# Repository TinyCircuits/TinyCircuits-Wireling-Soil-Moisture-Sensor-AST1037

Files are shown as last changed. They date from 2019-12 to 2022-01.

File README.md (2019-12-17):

# TinyCircuits Wireling Soil Moisture Sensor
# AST1037 Rev1

The design files are located under design_files/ for the TinyCircuits AST1037 Rev 1 PCB. This is a Wireling board which etects moisture in soil using the ATTiny25 and this plant tag shaped Whisker so you never have to guess when to water!

Format is in Cadsoft Eagle format - Eagle version 6.2 was used for the original design.

For more infomation on this, check out the product page at TinyCircuits.com

# License:

Design by TinyCircuits.
All design files are released under the Creative Commons Attribution Share-Alike 3.0 License, see the following link for details: http://creativecommons.org/licenses/by-sa/3.0

All text above must be included in any redistribution or derived design

This project uses designs and concepts developed as part of the Arduino project and the LilyPad project.  The TinyCircuits design files themselves (schematics, PCB and libraries) are not directly derived from these works' design files and have been created new, however the concepts and basic architecture behind the TinyDuino and TinyLily products are derived and we thank the hard work of the organizations below for their contributions to open-source hardware:
  
Original Arduino Uno Design by Team Arduino

LilyPad Arduino Design by Leah Buechley and Sparkfun Electronics

Please support the open-source hardware community

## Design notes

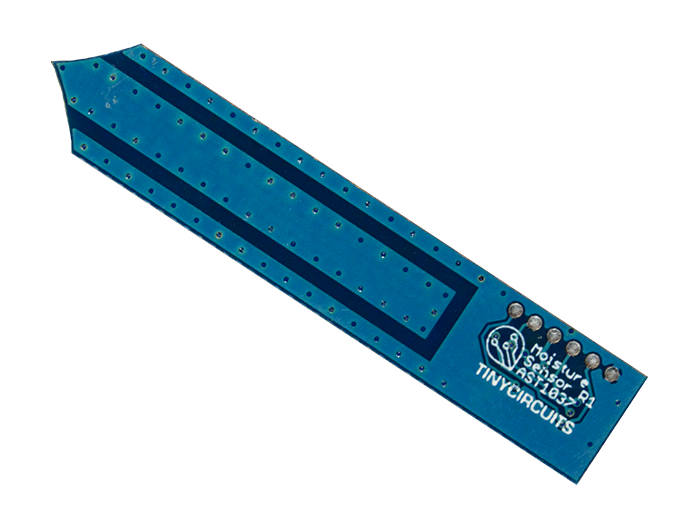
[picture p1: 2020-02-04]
images/AST1037-Product-Photo-02.png

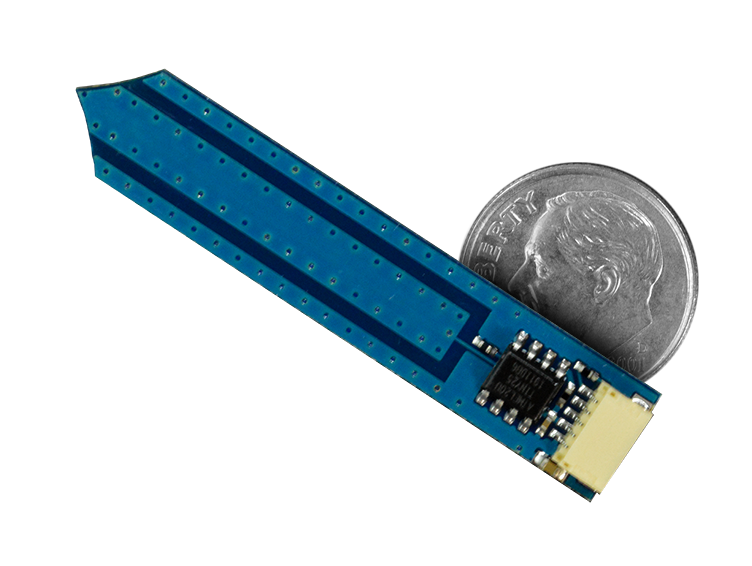
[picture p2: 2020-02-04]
images/AST1037-Product-Photo-03.png

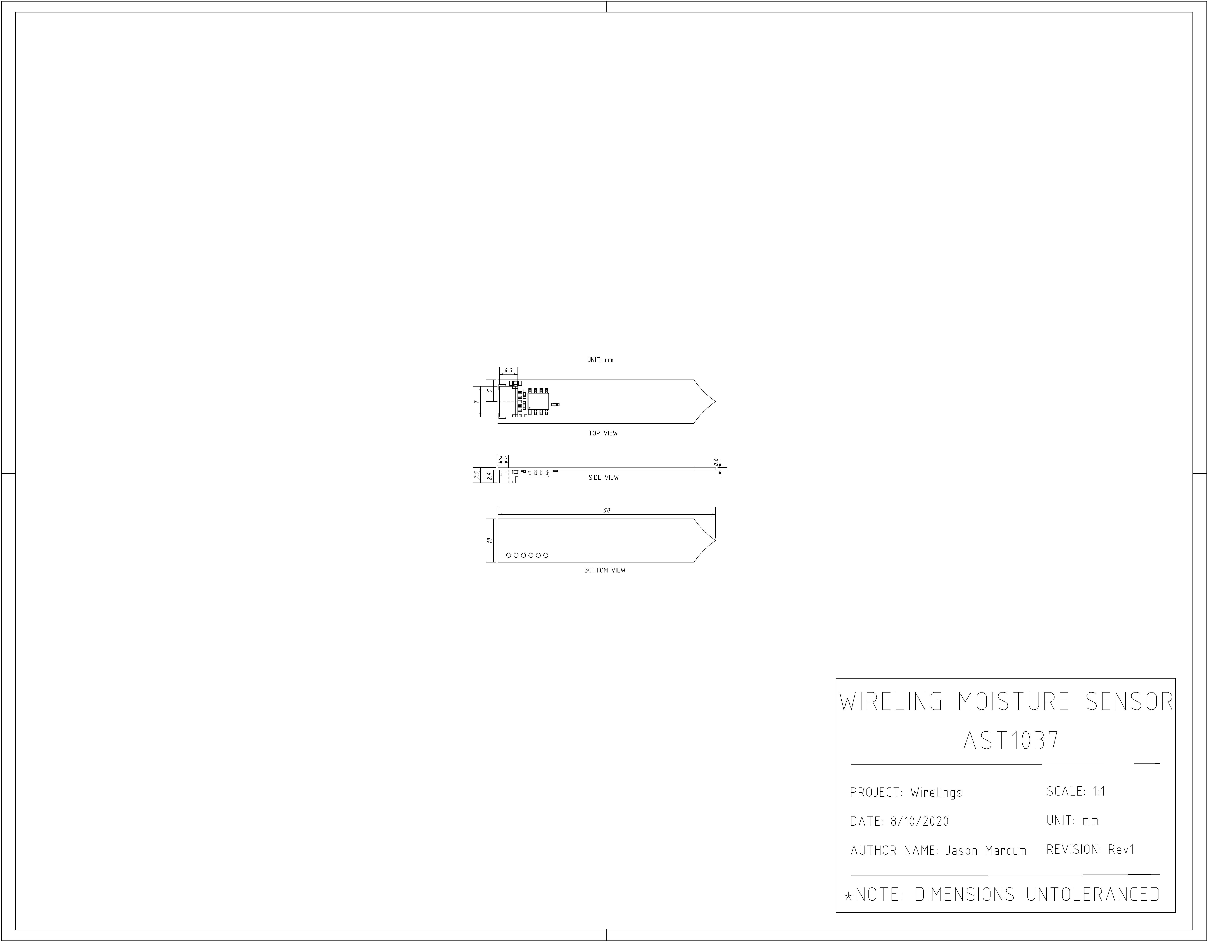
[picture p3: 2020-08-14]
cad/Wireling_MOISTURE_AST1037_REV1-DETAILED_DRAWING-PNG.png

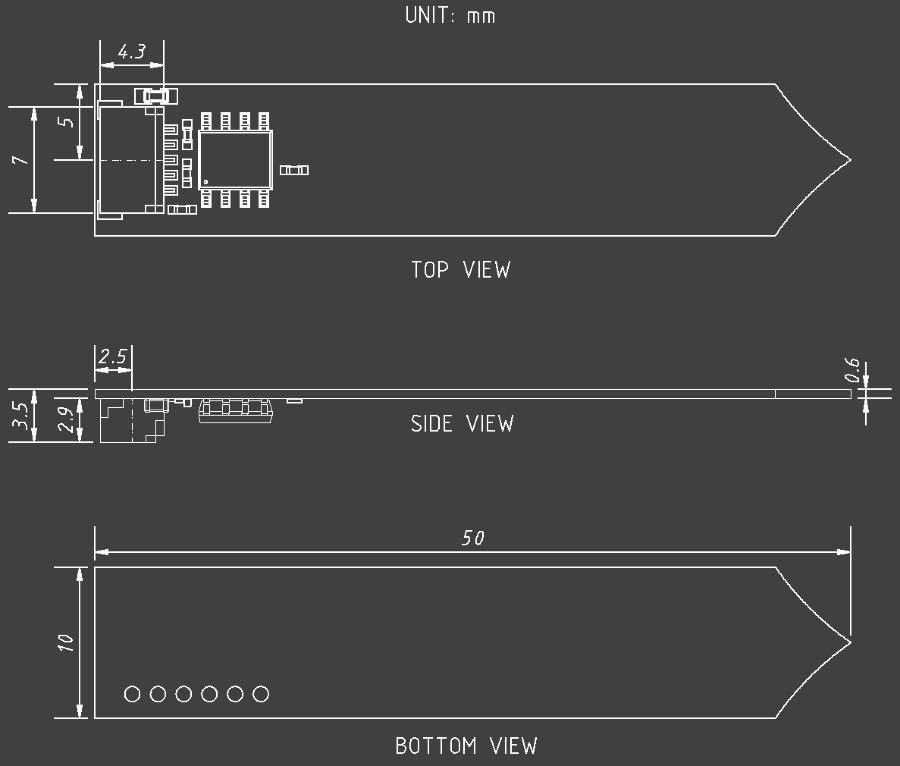
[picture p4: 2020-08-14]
cad/Wireling_MOISTURE_AST1037_REV1-DETAILED_DRAWING_COMPACT-PNG.png

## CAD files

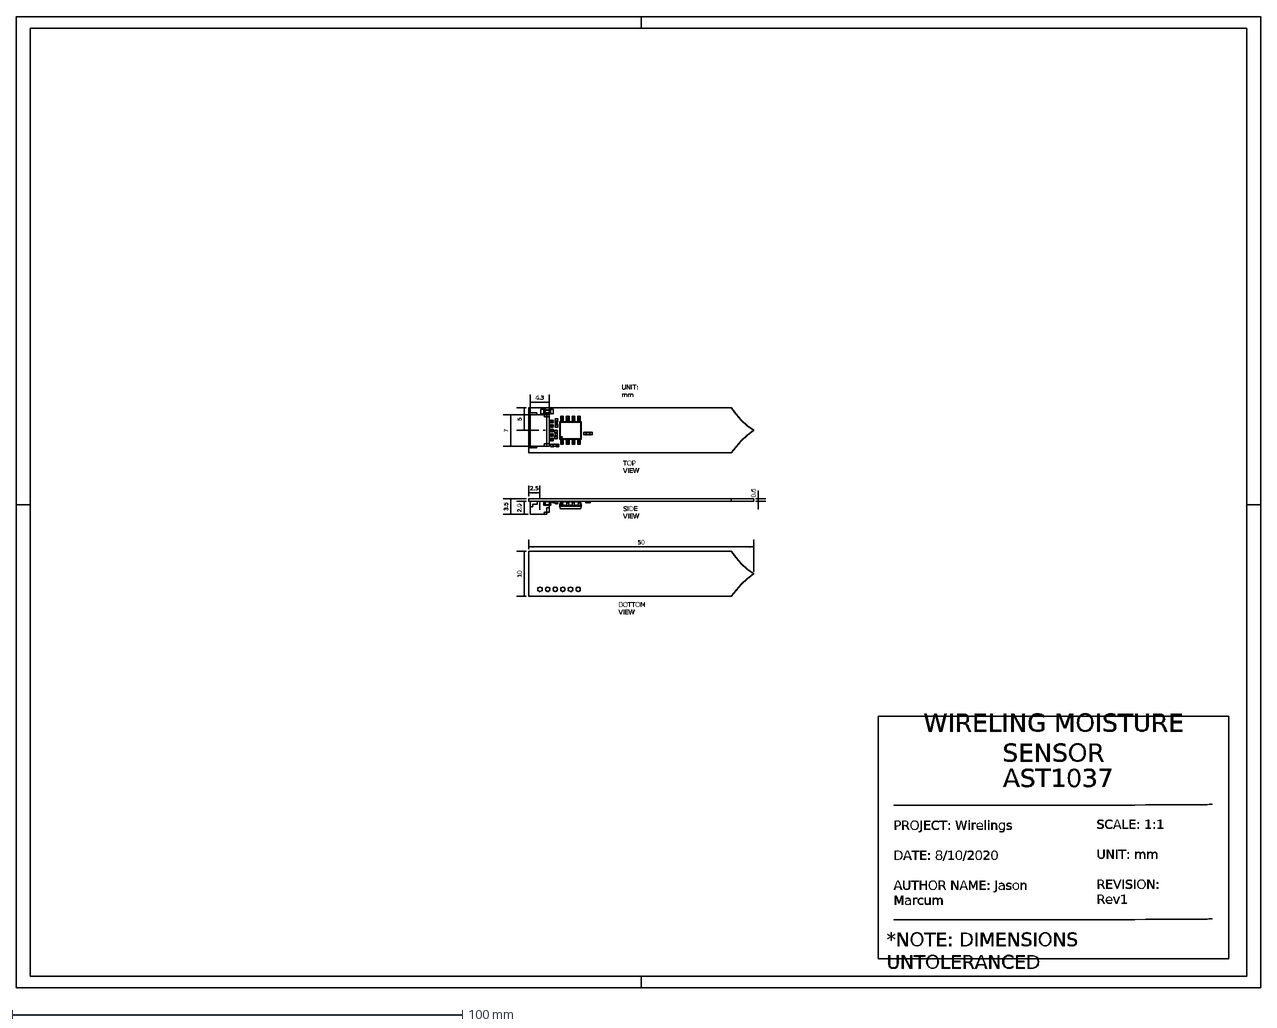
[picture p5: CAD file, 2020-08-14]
cad/Wireling_MOISTURE_AST1037_REV1-DETAILED_DRAWING-DXF.dxf
*NOTE: DIMENSIONS UNTOLERANCED
SCALE: 1:1 UNIT: mm REVISION: Rev1
2.5
2.9
3.5
0.6
SIDE VIEW
4.3
7
5
TOP VIEW
50
10
BOTTOM VIEW
WIRELING MOISTURE SENSOR
AST1037
PROJECT: Wirelings DATE: 8/10/2020 AUTHOR NAME: Jason Marcum
UNIT: mm

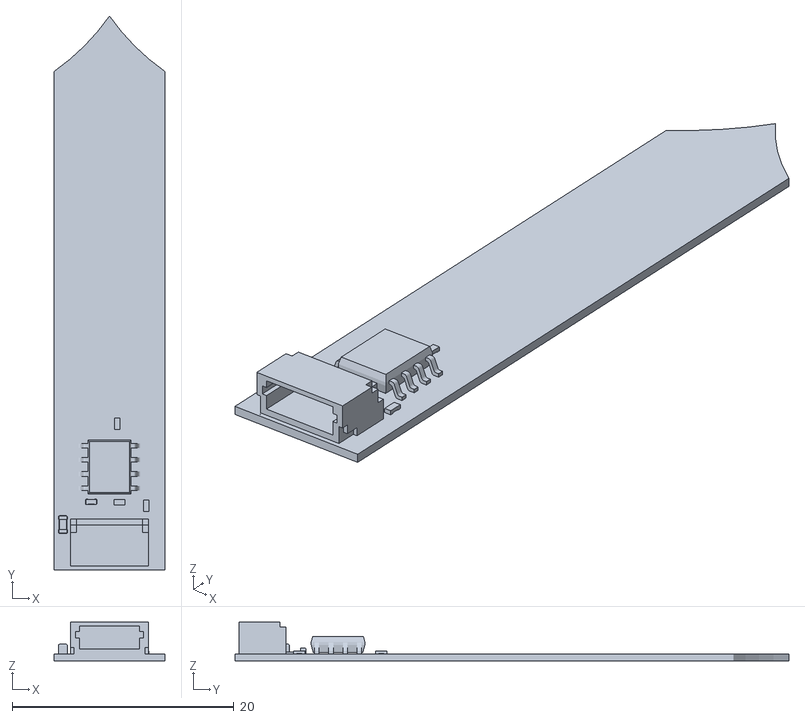
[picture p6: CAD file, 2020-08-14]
cad/Wireling_MOISTURE_AST1037_REV1-STL.stl
10.0 x 50.0 x 3.50

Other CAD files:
cad/Wireling_MOISTURE_AST1037_REV1-IGES.iges
cad/Wireling_MOISTURE_AST1037_REV1-STEP.step

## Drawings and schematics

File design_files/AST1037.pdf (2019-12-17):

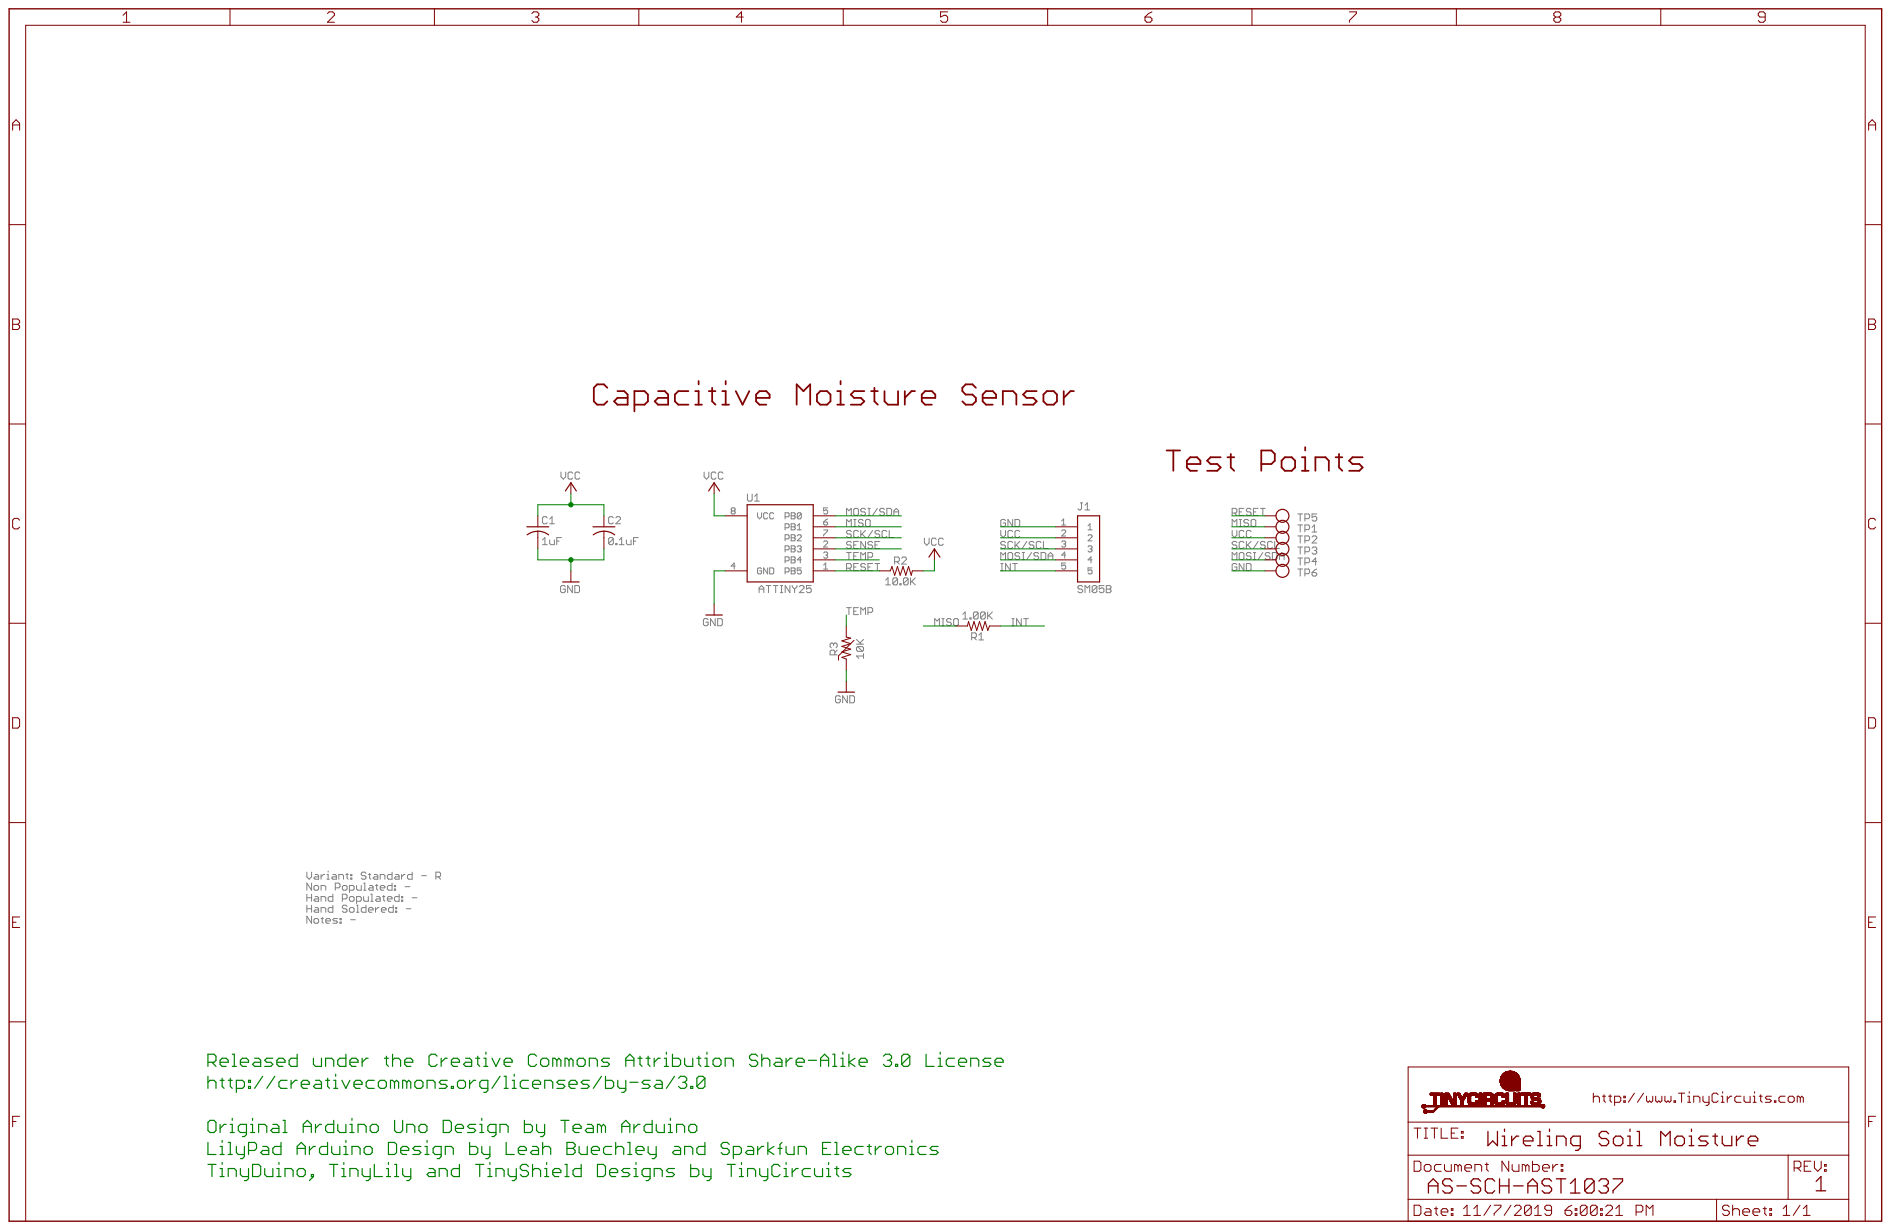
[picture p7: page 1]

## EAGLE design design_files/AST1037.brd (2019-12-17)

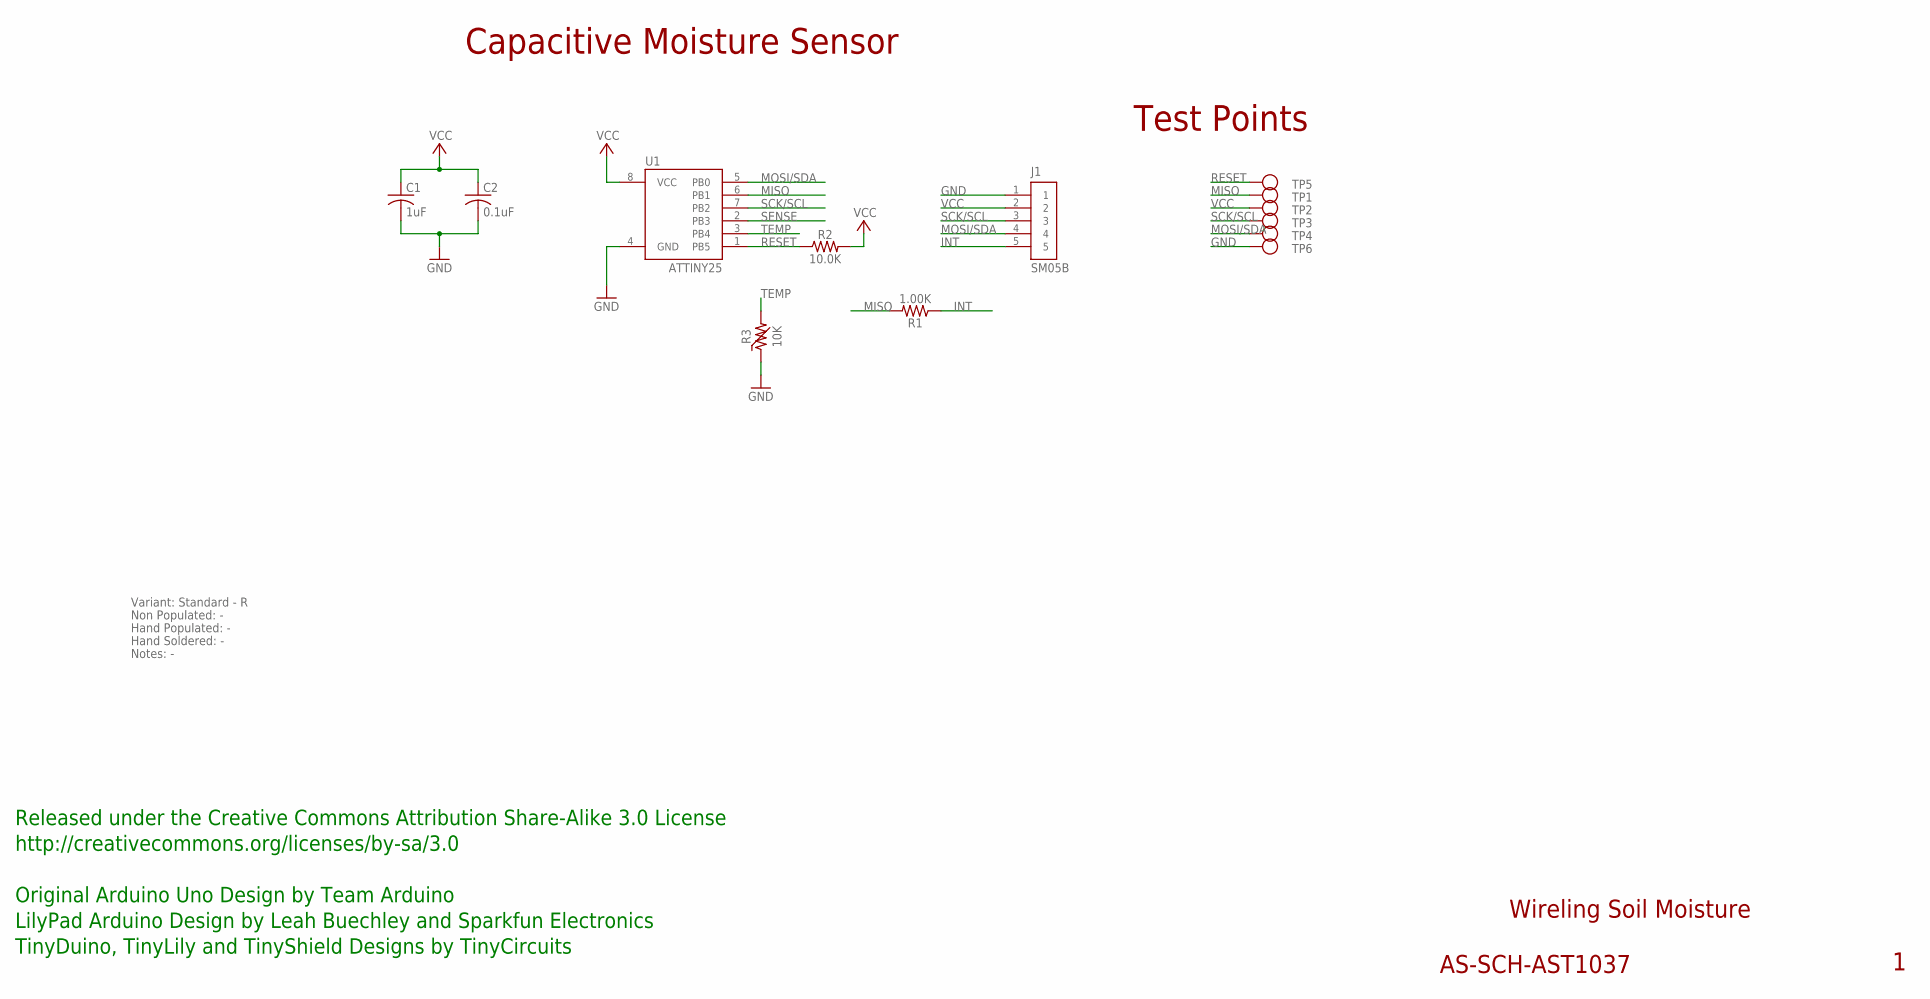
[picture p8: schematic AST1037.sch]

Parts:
C1: 1uF; C0603; PARTNO AS-ITM-00410
C2: 0.1uF; C0402
J1: SM05B; JST_SH_5X1
R1: 1.00K; 0402; PARTNO AS-ITM-00003
R2: 10.0K; 0402
R3: 10K; 0402
TP1, TP2, TP3, TP4, TP5, TP6: TEST_POINT; TEST_POINT_1MM
U1: ATTINY25; SO-08-COMPACT

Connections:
GND: C1.2, C2.2, J1.1, R3.1, TP6.P$1, U1.4 (GND)
INT: J1.5, R1.1
MISO: R1.2, TP1.P$1, U1.6 (PB1)
MOSI/SDA: J1.4, TP4.P$1, U1.5 (PB0)
RESET: R2.1, TP5.P$1, U1.1 (PB5)
SCK/SCL: J1.3, TP3.P$1, U1.7 (PB2)
SENSE: U1.2 (PB3)
TEMP: R3.2, U1.3 (PB4)
VCC: C1.1, C2.1, J1.2, R2.2, TP2.P$1, U1.8 (VCC)

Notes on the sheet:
Wireling Soil Moisture
AS-SCH-AST1037
Capacitive Moisture Sensor
Released under the Creative Commons Attribution Share-Alike 3.0 License
http://creativecommons.org/licenses/by-sa/3.0
Original Arduino Uno Design by Team Arduino
TinyDuino, TinyLily and TinyShield Designs by TinyCircuits
LilyPad Arduino Design by Leah Buechley and Sparkfun Electronics
Test Points
Non Populated: -
Hand Populated: -
Hand Soldered: -
Variant: Standard - R
Notes: -

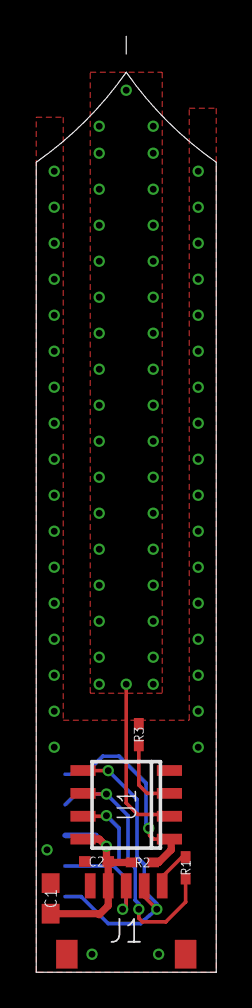
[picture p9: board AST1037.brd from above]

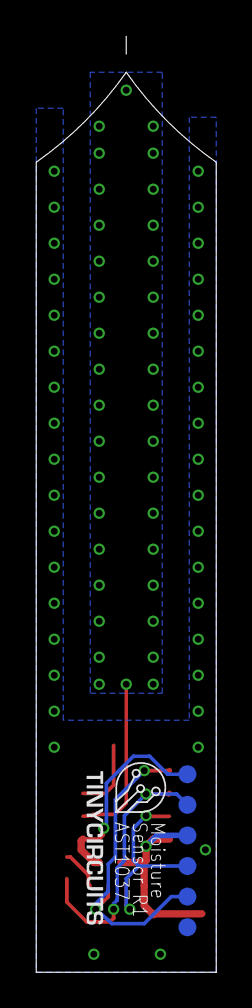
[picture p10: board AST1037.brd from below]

Board: 2 copper layers, 10.0 x 52.0 mm, 14 parts (6 on the bottom side), 8 nets.

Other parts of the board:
U$1: DOCFIELD-TINYCIRCUITS-PCB

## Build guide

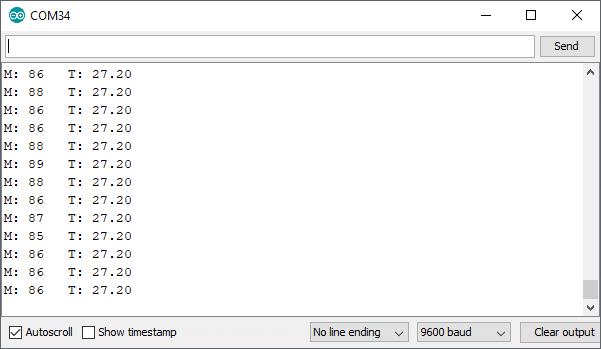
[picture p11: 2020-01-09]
images/AST1037-Tutorial-Image-03.png

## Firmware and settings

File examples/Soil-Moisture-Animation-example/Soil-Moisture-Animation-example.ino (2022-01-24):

/************************************************************************
 * Soil Moisture Wireling TinyScreen+ Animation Sketch
 * Port 0: Soil Moisture Sensor Wireling
 * 
 * This program will display an animation for the moisture levels read 
 * on a scale of 0-100 by the soil moisture sensor.
 * 
 * Hardware by: TinyCircuits
 * Written by: Jason Marcum & Laveréna Wienclaw for TinyCircuits
 *
 * Initiated: July 2019 
 * Updated: January 2021
 *  - updated to be compatible with the ATtiny25 library used by the Soil
 *  Moisture Sensor Wireling
 ************************************************************************/

#include <Wire.h>
#include <SPI.h>
#include <TinyScreen.h>
#include "TinyAnimation.h"
#include <Wireling.h>
#include <ATtiny25.h>      // For ATtiny25 sensor on the Soil Moisture Sensor Wireling

//Library must be passed the board type
//TinyScreenDefault for TinyScreen shields
//TinyScreenAlternate for alternate address TinyScreen shields
//TinyScreenPlus for TinyScreen+
TinyScreen display = TinyScreen(TinyScreenPlus);

// ***Setup objects for displaying on the screen***

//This is an 8 x 5 pixel bitmap using TS library color definitions for raindrop/watering animation
unsigned char RainDrop[8*5]={
  TS_8b_Black, TS_8b_Black, TS_8b_Blue, TS_8b_Black, TS_8b_Black,
  TS_8b_Black, TS_8b_Blue, TS_8b_Blue,  TS_8b_Blue,  TS_8b_Black,
  TS_8b_Black, TS_8b_Blue, TS_8b_Blue,  TS_8b_Blue,  TS_8b_Black,
  TS_8b_Blue,  TS_8b_White, TS_8b_Blue,  TS_8b_Blue,  TS_8b_Blue,
  TS_8b_Blue,  TS_8b_Blue, TS_8b_White,  TS_8b_Blue,  TS_8b_Blue,
  TS_8b_Black, TS_8b_Blue, TS_8b_Blue,  TS_8b_Blue,  TS_8b_Black
};

PercentBarHorizontal bar(display, 2, 2, 94, 14, TS_8b_Gray, TS_8b_Blue, TS_8b_Green, 0, "dry", "wet", true);
IdleCircle idle(display, 75, 47, TS_8b_Gray, TS_8b_White, 9, 1, 3);
FallDownSprite animator(display, 70, 34, 5, 5, 5, 100, RainDrop);


/* * * * * * MOISTURE SENSOR * * * * * * */
#define MOISTURE_PORT 0 
ATtiny25 moisture_sensor;
float moistness = 0.0;  // Variable that keeps raw reading from the sensor


// ***Setup variables for getting readings from the moisture sensor***
// These are close to correct values but calibration will make it more accurate
int offset = 0; // This is the value read off by the Moisture Sensor when completely dry
int range = 100; // The range og values from completely dry (700) to being submerged in water (964)

// Used to smooth out readings from moisture sensor 
// (reduces bar jitter due to fast refresh rate/readings)
int moist_readings_counter = 0;
float moist_readings_sum = 0.0;

const int avg_moist_size = 8;
float avg_moistness = 0.0; // Actual avg moisture
float avg_moistness_last = 0.0; // Used to turn on animation


// 0 = no calibration
// 1 = display hold sensor in air
// 2 = take dry readings display hold sensor in water
// 3 = take wet readings end
byte calibration_flag = 0;
bool write_once_cali_flag = false;

bool animation_on = false; // Used to display certain animations at correct times

// Make Serial Monitor compatible for all TinyCircuits processors
#if defined(ARDUINO_ARCH_AVR)
  #define SerialMonitorInterface Serial
#elif defined(ARDUINO_ARCH_SAMD)
  #define SerialMonitorInterface SerialUSB
#endif


void setup(void) {
  Wire.begin(); //initialize I2C before we can initialize TinyScreen- not needed for TinyScreen+
  display.begin();
  SerialMonitorInterface.begin(9600);
  
  display.setBrightness(10);

  // Select the port the Wireling (moisture sensor) is connected to on the Adapter board
  Wireling.begin();
  Wireling.selectPort(MOISTURE_PORT);
  delay(100);

  // Take sensor reading to get an initial value for displaying the moisture bar
  moistness = moisture_sensor.readMoisture();
  moistness = (moistness - offset) / range;

  // Apply the letters to the screen once so we don't have to every tick
  bar.updateBarEndInfo();

  // Show a message about what the plant is doing
  ShowIdleMessage();
}

void loop() {
  // Only show monitoring information if not currently in calibration mode
  if(calibration_flag == 0){
    // animation is on? Make raindrops!
    if(animation_on){
      // If got to the last frame then stop animation next time
      if(animator.tick()){
        animation_on = false;
        
        // Show a message about what the plant is doing
        ShowIdleMessage();
      }
    }
  
    // If no animation/not being watered show idle circle
    if(!animation_on){
      idle.tick();
    }
    
    // Get a moisture value
    moistness = moisture_sensor.readMoisture();
  
    // Offset the reading to put in range of 0 to 100
    moistness = (moistness - offset) / range;
  
    // Handle getting an average and updating the percent bar
    HandleMostureReading(moistness);
  
    // Press button by power switch to start sensor cailbration or enter c
    if(display.getButtons(TSButtonUpperRight) || (SerialMonitorInterface.available() > 0 && SerialMonitorInterface.read() == 'c')){
      SerialMonitorInterface.println("\nCalibration started!\n");
      calibration_flag++;
      write_once_cali_flag = false;
      
      // Delay so last button press doesn't register right away
      delay(800);
    }
  }

  // Handle the calibration steps
  if(calibration_flag >= 1){
    if(display.getButtons(TSButtonUpperRight|TSButtonUpperLeft|TSButtonLowerRight|TSButtonLowerLeft) || (SerialMonitorInterface.available() > 0 && SerialMonitorInterface.read() == 'n')){
      calibration_flag++; // Move on to next stwp of calibration
      write_once_cali_flag = false;
      
      // Delay so last button press doesn't register right away
      delay(800);
    }

    // Have to use flags since infinite loops don't allow new input from serial
    CalibrateMoisutreSensor();
  }
}

// Handles averaging and updating percent bar
void HandleMostureReading(float offset_moisture_reading){
  // Sum for avg's numerator
  moist_readings_sum += offset_moisture_reading;

  // Increment the tracker/counter
  moist_readings_counter += 1;

  // Calculate the average when the counter reaches the size
  if(moist_readings_counter == avg_moist_size){
    avg_moistness = moist_readings_sum/avg_moist_size;

    // Reset these for next average/reading
    moist_readings_counter = 0;
    moist_readings_sum = 0.0;
  }

  // Animate/update text for the percent bar
  bar.tick(avg_moistness);

  // Display plant status to the serial monitor
  if(!animation_on){
    SerialMonitorInterface.print("Plant is -> IDLE | Moisture level = ");
  }else{
    SerialMonitorInterface.print("Plant is -> HYDRATING | Moisture level = ");
  }

  // Display the moisture level to the serial monitor
  SerialMonitorInterface.println(avg_moistness);

  // Looks like a big jump, turn on animation and clear idle animation
  if(avg_moistness - avg_moistness_last > 0.1){
    animation_on = true;

    // Show a message about what the plant is doing
    ShowHydratingMessage();
    
    idle.erase();
  }

  avg_moistness_last = avg_moistness;
}

void ShowHydratingMessage(){
  display.setFont(thinPixel7_10ptFontInfo);
  display.fontColor(TS_8b_Green, TS_8b_Black);
  display.setCursor(0, 40);
  display.println("Plant is:");
  display.setCursor(0, 50);
  display.println("->");
  display.fontColor(TS_8b_Blue, TS_8b_Black);
  display.setCursor(11, 50);
  display.println("Hydrating");
}

void ShowIdleMessage(){
  display.setFont(thinPixel7_10ptFontInfo);
  display.fontColor(TS_8b_Green, TS_8b_Black);
  display.setCursor(0, 40);
  display.println("Plant is:");
  display.setCursor(0, 50);
  display.println("->");
  display.fontColor(TS_8b_Gray, TS_8b_Black);
  display.setCursor(11, 50);
  display.println("Idle     ");
}




// Used to calibrate the moisture sensor
void CalibrateMoisutreSensor(){

  // Only write stuff to the screen once, avoids flicker
  if(write_once_cali_flag)
    return;

  // Handle each flag for the calibration process
  switch(calibration_flag){
    case 1:
      display.clearScreen();
      display.setFont(thinPixel7_10ptFontInfo);
      display.fontColor(TS_8b_Green,TS_8b_Black);
      display.setCursor(0, 0);
      
      display.println("Hold sensor in the");
      display.setCursor(0, 10);
      display.fontColor(0x90, TS_8b_Black);
      display.println("AIR");
      display.fontColor(TS_8b_Green, TS_8b_Black);
      display.setCursor(22, 10);
      display.println("and press any");
      display.setCursor(0, 20);
      display.println("button");
      display.setCursor(0, 30);
      display.fontColor(TS_8b_Red, TS_8b_Black);
      display.println("(hold by wire only!)");
      display.fontColor(TS_8b_Green, TS_8b_Black);
      SerialMonitorInterface.println("Hold the sensor in the AIR and press any button or enter 'n' (hold by the wire only!)");
      write_once_cali_flag = true;
    break;
    case 2:
    
      display.clearScreen();
      display.setCursor(0, 0);
      display.println("Keep holding");
      SerialMonitorInterface.println("Keep holding the sensor");
      display.setCursor(0, 10);
      display.println("Taking readings...");
      SerialMonitorInterface.println("Taking readings...");
    
      // Take the dry readings
      moist_readings_sum = 0;
    
      for(int i=0; i<100; i++){
        
        moist_readings_sum += moisture_sensor.readMoisture();
    
        // Space readings apart
        delay(25);
      }
    
      // Dry readings are the offset (use average of 5 readings)
      offset = moist_readings_sum/100;
    
      display.clearScreen();
      display.setCursor(0, 0);
      display.println("Dry readings done");
      SerialMonitorInterface.println("Dry readings done");
      display.setCursor(0, 20);
      display.println("offset = " + String(offset));
      SerialMonitorInterface.println("offset = " + String(offset));
      delay(2000);
      write_once_cali_flag = true;
    
      display.setCursor(0, 0);
      display.clearScreen();
      display.println("Submerge sensor in");
      display.setCursor(0, 10);
      display.fontColor(TS_8b_Blue, TS_8b_Black);
      display.println("WATER");
      display.fontColor(TS_8b_Green, TS_8b_Black);
      display.setCursor(31, 10);
      display.println("and press any");
      display.setCursor(0, 20);
      display.println("button");
      SerialMonitorInterface.println("Submerge the sensor in WATER and press any button or enter 'n'");
      write_once_cali_flag = true;
    break;
    case 3:
      display.clearScreen();
      display.setCursor(0, 0);
      display.println("Keep holding");
      SerialMonitorInterface.println("Keep holding the sensor");
      display.setCursor(0, 10);
      display.println("Taking readings...");
      SerialMonitorInterface.println("Taking readings...");
    
      // Take the submerged readings
      moist_readings_sum = 0;
    
      for(int i=0; i<100; i++){
        
        moist_readings_sum += moisture_sensor.readMoisture();
    
        // Space readings apart
        delay(25);
      }
    
      range = (moist_readings_sum/100) - offset;
    
      // Range wasn't big enough, error!
      if(range <= 0){
        display.clearScreen();
        display.setCursor(0, 0);
        display.fontColor(TS_8b_Red, TS_8b_Black);
        display.println("Range not big");
        display.setCursor(0, 10);
        display.println("enough!");
        display.setCursor(0, 30);
        display.fontColor(TS_8b_Green, TS_8b_Black);
        display.println("Set to defaults...");
        SerialMonitorInterface.println("The range is not big enough! Setting offset and range back to defaults");
    
        // Give an extra second to read error
        delay(1000);
    
        offset = 0;
        range = 100;
      }else{
        display.clearScreen();
        display.setCursor(0, 0);
        display.println("Wet readings done");
        SerialMonitorInterface.println("Wet readings done");
        display.setCursor(0, 20);
        display.println("range = " + String(range));
        SerialMonitorInterface.println("range = " + String(range));
      }
    
      // Delay so last button press doesn't register right away and to give time to read
      delay(2000);
      display.clearScreen();
      delay(100);
      moist_readings_sum = 0;
      moist_readings_counter = 0;
      bar.updateBarEndInfo();
    
      // Show a message about what the plant is doing
      ShowIdleMessage();

      calibration_flag = 0;
    break;
  }
}

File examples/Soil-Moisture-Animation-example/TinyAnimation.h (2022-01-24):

// Written by Jason Marcum for TinyCircuits
// Initiated: July 2019


#ifndef TinyAnimation_h
#define TinyAnimation_h

// For Color definitions
#include "TinyScreen.h"


class PercentBarHorizontal{
public:
    PercentBarHorizontal(TinyScreen display_, int x_, int y_, int width_, int height_, uint8_t outline_color_, uint8_t bar_color_, uint8_t font_color_, float percent_, char *left_end_, char *right_end_, bool show_percentage_) 
    : display(display_)
    , x(x_)
    , y(y_)
    , width(width_)
    , height(height_)
    , percent(percent_)
    , left_end(left_end_)
    , right_end(right_end_)
    , show_percentage(show_percentage_)
    , outline_color(outline_color_)
    , bar_color(bar_color_)
    , font_color(font_color_)
    {}
    
    // Clear/overwrite the graphic with black
    void erase();

    // Sets the end bar text info
    void updateBarEndInfo();
    
    // Show the next frame if it is time, otherwise keep track of the tick/speed
    void tick(float percent_);
    
private:
    TinyScreen display;
    
    // Information about the graphic and how it behaves/looks
    int x;
    int y;
    int width;
    int height;
    float percent = 0.0;
    float last_percent = percent;
    char *left_end;
    char *right_end;
    bool show_percentage;
    uint8_t outline_color;
    uint8_t bar_color;
    uint8_t font_color;
};



class IdleCircle{
public:

    // Rotation speed is frame per rotation_slowness_ (ticks). If rotation_slowness_ = 4, then 1 frame every 4 ticks (frame/rotation_slowness_)
    IdleCircle(TinyScreen display_, int x_, int y_, uint8_t trail_color_, uint8_t head_color_, int radius_, int thickness_, int rotation_slowness_) 
    : display(display_)
    , x(x_)
    , y(y_)
    , radius(radius_)
    , thickness(thickness_)
    , rotation_slowness(rotation_slowness_)
    , trail_color(trail_color)
    , head_color(head_color_)
    {}
    
    // Clear/overwrite the graphic with black
    void erase();
    
    // Show the next frame if it is time, otherwise keep track of the tick/speed
    void tick();
    
private:
    TinyScreen display;
    
    // Information about the graphic and how it behaves/looks
    int x;
    int y;
    int radius;
    int thickness;
    int rotation_slowness;
    uint8_t trail_color;
    uint8_t head_color;

    // Internal stuff for the circle itself
    int tick_counter = 0;
    int tick_fallover_limit = rotation_slowness;
    float angle_step = 4;
    float angle_step_tracker = 0;
};



class FallDownSprite{
public:
    FallDownSprite(TinyScreen display_, int x_, int y_, int sprite_count_, int x_spacing_, int y_spacing_, int speed_, unsigned char *sprite_) 
    : display(display_)
    , x(x_)
    , y(y_)
    , sprite_count(sprite_count_)
    , x_spacing(x_spacing_)
    , y_spacing(y_spacing_)
    , speed(speed_)
    , sprite(sprite_)
    {}
    
    // Clear/overwrite the graphic with black
    void erase();
    
    // Show the next frame if it is time, otherwise keep track of the tick/speed
    // Returns true when it reaches the last frame, otherwise false 
    bool tick();
    
private:
    TinyScreen display;
    
    // Information about the graphic and how it behaves/looks
    int x;
    int y;
    int sprite_count;
    int x_spacing;
    int y_spacing;
    int speed;
    unsigned char *sprite;

    // Every 110 loops/ticks update the animation
    int animation_tick_size = speed;
    
    // Tracks how many ticks it has been
    int animation_tick_counter = 0;
    
    // Tracks current animation frame (changes every animation_tick_size)
    int animation_frame_counter = 0;

    int x_cur_pos = 0;
    int y_cur_pos = 0;
    
};

#endif

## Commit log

2019-12-17 updated documentation
    [AST1037.brd, AST1037.sch]
2020-01-14 these variable labels were just WRONG
    [Soil-Moisture-Wireling_example.ino]
2020-08-14 Add CAD data
    [Wireling_MOISTURE_AST1037_REV1-DETAILED_DRAWING-DXF.dxf, Wireling_MOISTURE_AST1037_REV1-IGES.iges, Wireling_MOISTURE_AST1037_REV1-STEP.step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]
